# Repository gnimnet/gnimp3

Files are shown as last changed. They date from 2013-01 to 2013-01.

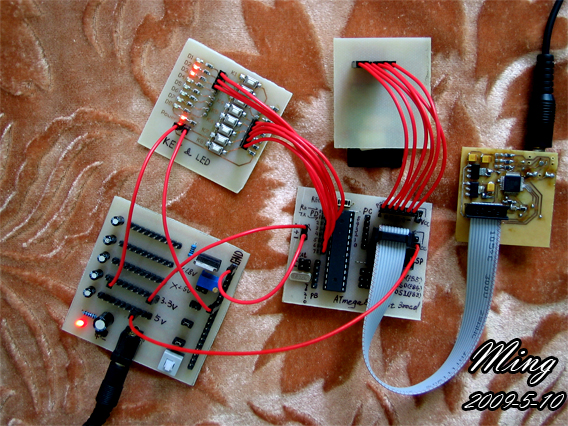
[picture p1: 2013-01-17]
modules.jpeg

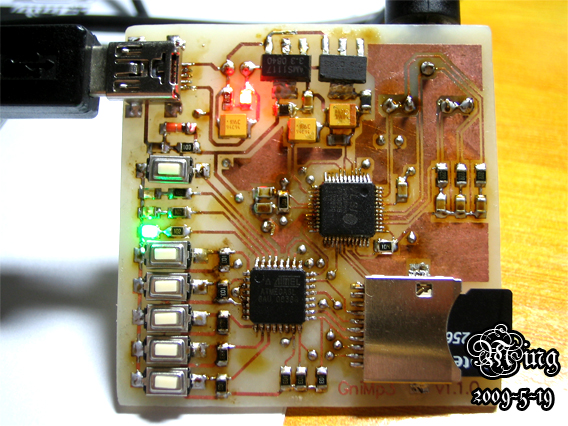
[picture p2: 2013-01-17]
final1.jpeg

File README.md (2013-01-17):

gnimp3
======

基于VS1003的mp3

这是我很满意的一个硬件设计，用自己的MP3还是爽啊
这个电子设计是我相当满意的一个，板子也布的很满意，毕竟单层板...我也不容易啊...这个MP3并没有屏幕，从TF卡里读音乐文件数据，曲目最大支持到70首，有全部循环、单曲循环、随机播放3个模式。供电有个迷你USB口，还有个接排针(我拿来接锂电池)。我是从代码到画PCB，热转印，焊接一手完成，所以这个尤物的纪念意义更大。我现在MP3一直用这个了。

很早就想做一个稍微使用点，感觉牛一点的电子设计，也很早就像打造一个属于自己的MP3，不过硬件功底又不是一时半会能弄起来，从大三开始(其实早些也学)画大把精力在硬件上面，从51到AVR，一直到这个项目，算是我AVR的结业项目了，下来应该要转去玩ARM7了...

其实这个东西做起来很辛苦的，FAT代码是2009寒假写的，然后在3月份就完成了ATmega64的版本(是在一个开发板上，我重写代码并把自己的FAT移植到AVR上)，但PCB的过程却极其郁闷，其实我的设计一直是对的，但是被那万恶的焊锡膏还得一个月没吃好睡好，不过也得谢谢它让我把这个PCB重画了无数遍...最后的体积减小了一倍呢(当然和我最后改用TF卡座也有关)...毕竟我是4月份买到热转印机才开始转印PCB，之前都是万用板。水平也是练出来的么～有志者事竟成乎～

要学习的话，下载链接的东西都有用的；如果只是仿制，那么测试代码没用的，把别的下载下来，然后热转印再把HEX烧到芯片里面就ok...

开发环境
AVR Studio 4.16
WinAVR-20070525
Protel DXP 2004

使用芯片
ATmega8
VS1003B

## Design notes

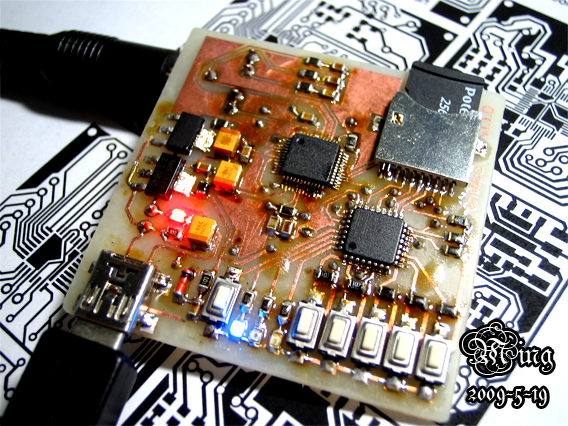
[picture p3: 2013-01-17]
final2.jpeg

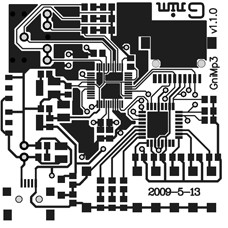
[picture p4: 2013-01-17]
toplayer.jpg

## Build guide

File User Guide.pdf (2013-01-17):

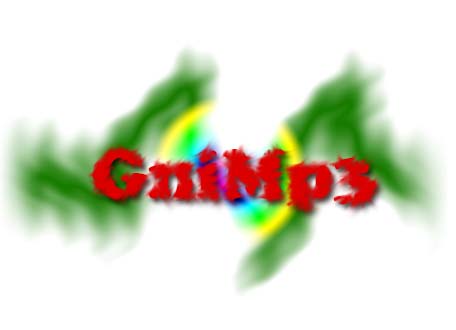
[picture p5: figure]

# Version 1.1.X User Guide By Ming

User Guide(Version 1.1.X)

# MP3 Interface

1 个复位按键
5 个操作按键
1 个电源指示灯
3 个模式指示灯
使用 TF 卡提供音乐数据
使用 3.5mm 耳机
使用 MiniUSB 或跳线供电

1 Key for Reset
5 Keys for Operate
1 LED for Power
3 LEDs for Mode
Use TF card for music data
Use 3.5mm Earphone
MiniUSB or Jumper for power supply

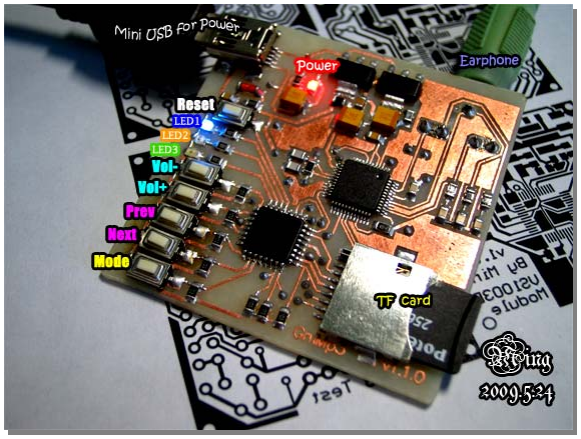
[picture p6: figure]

User Guide(Version 1.1.X)

# Get Start

1. 插入 TF 卡：
在卡座卡入 TF 卡，要求 TF 卡应当格式化为 FAT 文件系统（FAT32/16 均可）
2. 供电：
使用 MiniUSB 或者背面的排针跳线供电，供电电压 3.3v—9v
（建议使用 USB 或者 3.7v 锂电池）
3.MP3 初始化：
在供电后 MP3 将先进行硬件初始化，改步骤如下：
(1)初始化 SD 卡（LED1、LED2、LED3 灭）
(2)初始化 FAT 文件系统信息（LED2、LED3 亮，LED1 灭） (3)初始化 MP3 解码芯片 VS1003B（LED1、LED3 亮，LED2 灭） (4)初始化音乐列表（LED1、LED2 亮，LED3 灭） (5)从播放列表第一首开始进行全部曲目循环播放
对于每一步状态有不同的 LED 指示来确认硬件故障
停在第一步，请检查 SD 卡正确性
停在第二步，请检查 SD 卡格式化的文件系统是否正确，或 SD 卡已坏 停在第三步，可能 VS1003B 解码芯片已坏…
停在第四步，请检查 SD 卡是否无歌曲
4.调整使用：
使用 Mode 按键来切换模式，三个 LED 对应 3 种播放模式 LED1——全部循环，LED2——单曲循环，LED3——随机播放 按下按键按如下顺序切换：
全部循环单曲循环随机播放全部循环……
音量由 Vol-和 Vol+按键来操作，按住不放会进行连续的音量调整
曲目切换由 Prev 和 Next 按键来操作，对于全部循环和单曲循环两个按键按音乐列表切换 上一首和下一首，对于随机模式则任意跳到音乐列表中的一首。

注：
支持音乐文件格式:MP3/WMA/WAV/MID
由于 ATmega8 的 SRAM 限制，音乐列表只保存 70 首，对于 TF 卡多于 70 首音乐的，在搜 索 70 首之后将忽略其他音乐文件。
手最好不要接触到 VS1003B 的晶振引脚，可能引起解码芯片停止工作（可通过复位键重新 初始化解码芯片）
使用电池供电时，在电池快没电的时候状态 LED 会变暗

User Guide(Version 1.1.X)

# PCB Top Layer

这里提供一张 Version 1.1.0 的 PCB 顶层 电路的设计为单层板，这个是第一块通过的板子的 PCB 图

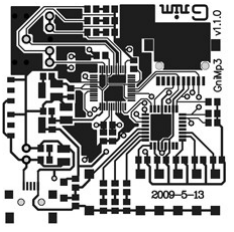
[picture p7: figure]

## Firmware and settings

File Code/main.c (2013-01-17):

#include <avr/io.h>
#include <util/delay.h>
#include "MMC_SD/MMC_SD.h"
#include "FAT/FAT.h"
#include "VS1003B/VS1003B.h"

#define PLAY_FILE_BUF_SIZE	512	//必须是32的整数倍
#define SONG_CLUS_LIST_SIZE	70	//列表大小
#define MAX_SEARCH_DEPTH	5	//文件夹搜索最大深度
#define MODE_NUMS			3	//模式数量

#define LEDPORT	PORTD
#define LEDDDR	DDRD
#define LED1	PD0
#define LED2	PD1
#define LED3	PD2

#define KEYPIN	PIND
#define KEYDDR	DDRD
#define KEY1	PD3
#define KEY2	PD4
#define KEY3	PD5
#define KEY4	PD6
#define KEY5	PD7

void PrintFileName(DWORD DirFristClus,BYTE index);

void SearchSongs();
BYTE ChangePWD(DWORD * PWDClusAdd,WORD Offset);
BYTE PlayFile(DWORD PWDClus,WORD Offset);
void ChangeVol(uchar dec);
uchar GetKey();
void MyDelay(uint ms);
void MaskVS1003B();


DWORD SongClusList[SONG_CLUS_LIST_SIZE];//歌曲所在目录簇号
BYTE SongIndex[SONG_CLUS_LIST_SIZE];//歌曲对应目录项偏移
BYTE TotalNum;//总歌曲数目
uchar NowVol;//当前音量
uchar PlayMode;//播放模式 0--全部循环，1--单曲循环，2--随机播放

int main(void){
	BYTE NowPlay=0,tmp;
	MaskVS1003B();//屏蔽VS1003对SD初始化影响
	NowVol=0x28;
	LEDDDR|=(1<<LED1)|(1<<LED2)|(1<<LED3);//LED端口设为输出
	KEYDDR&=~((1<<KEY1)|(1<<KEY2)|(1<<KEY3)|(1<<KEY4)|(1<<KEY5));//按键端口设为输入
	TCCR0=0x01;//打开Timer0用作随机数种子
	LEDPORT|=(1<<LED1)|(1<<LED2)|(1<<LED3);
	//初始化SD卡信息
	while(SD_Init()!=0)
		;
	LEDPORT=~(1<<LED1);
	//初始化FAT信息
	if(InitFAT()>1){//>2则为FAT12或初始化出错
		while(1);//死循环等待复位
	}
	LEDPORT=~(1<<LED2);
	//初始化VS1003B
	while(VS1003B_Init()==1){
		MyDelay(100);//等待0.1秒重试
	}
	LEDPORT=~(1<<LED3);
	//查找歌曲
	SearchSongs();
	if(TotalNum==0){
		while(1);//没有歌曲
	}
	PlayMode=0;
	LEDPORT=(1<<PlayMode);
	//进入播放循环
	while(1){
		VS1003B_SoftReset();
		tmp=PlayFile(SongClusList[NowPlay],SongIndex[NowPlay]);//播放歌曲
		if(PlayMode==0 || PlayMode==1){
			if(tmp==0 && PlayMode==0){//歌曲播放完毕且为全部循环播放，切换下一首
				if(NowPlay<TotalNum-1)
					NowPlay++;
				else
					NowPlay=0;
			}
			else if(tmp==0xFF){//按下下一首按键
				if(NowPlay<TotalNum-1)
					NowPlay++;
				else
					NowPlay=0;
				MyDelay(10);
			}
			else if(tmp==0xFE){//按下上一首按键
				if(NowPlay==0)
					NowPlay=TotalNum-1;
				else
					NowPlay--;
				MyDelay(10);
			}
		}
		else if(PlayMode==2){
			NowPlay=TCNT0;
			NowPlay%=TotalNum;
		}
	}
	return 0;
}

BYTE GetFileType(DWORD DirFristClus,BYTE index){//获取文件类型函数
	WORD totalnum=GetClusSize()/32;
	struct DIR DIRinfo;
	while(index>=totalnum){
		index-=totalnum;
		DirFristClus=GetNextClus(DirFristClus);//文件位于下一簇
	}
	if(GetDIRinfo(&DIRinfo,DirFristClus,index)!=0){//get file information
		return 0;//Read DIRinfo error!
	}
	if(DIRinfo.DIR_Name[0]==0x00)//End
		return 1;
	if(DIRinfo.DIR_Name[0]==0xE5)//Empty
		return 2;
	if(DIRinfo.DIR_Attr==ATTR_LONG_NAME)//Long File Name
		return 3;
	if(DIRinfo.DIR_Attr==ATTR_VOLUME_ID)
		return 4;
	else if(DIRinfo.DIR_Attr & ATTR_DIRECTORY)
		return 5;
	else{
		if(!(
		(DIRinfo.DIR_Name[8]=='M' && DIRinfo.DIR_Name[9]=='P' && DIRinfo.DIR_Name[10]=='3')||
		(DIRinfo.DIR_Name[8]=='W' && DIRinfo.DIR_Name[9]=='A' && DIRinfo.DIR_Name[10]=='V')||
		(DIRinfo.DIR_Name[8]=='M' && DIRinfo.DIR_Name[9]=='I' && DIRinfo.DIR_Name[10]=='D')||
		(DIRinfo.DIR_Name[8]=='W' && DIRinfo.DIR_Name[9]=='M' && DIRinfo.DIR_Name[10]=='A')
		)){
			return 6;//not a music file
		}
		return 7;//is a music file
	}
	return 8;//unknow file type
}

void SearchSongs(){//查找歌曲函数，用于初始化歌曲列表
	DWORD ClusPWD;//当前工作目录簇号
	BYTE IndexPWD[MAX_SEARCH_DEPTH];//当前工作目录簇号偏移
	BYTE NowLevel;//当前目录级数
	BYTE tmp;
	ClusPWD=GetRootClus();//从根目录开始
	IndexPWD[0]=0;//从0偏移开始找
	NowLevel=0;//当前目录为0级
	TotalNum=0;
	while(1){
		tmp=GetFileType(ClusPWD,IndexPWD[NowLevel]);
		if(tmp==0){//IO错误，重试
			continue;
		}
		else if(tmp==1){//当前目录搜索完毕
			if(NowLevel==0){
				return;//根目录则搜索结束
			}
			else{
				ChangePWD(&ClusPWD,1);//调回上级目录
				NowLevel--;
			}
		}
		else if(tmp==5){
			if(NowLevel<MAX_SEARCH_DEPTH){//未超过最大深度
				ChangePWD(&ClusPWD,IndexPWD[NowLevel]);
				NowLevel++;
				IndexPWD[NowLevel]=1;
			}
		}
		else if(tmp==7){//记录该文件
			SongClusList[TotalNum]=ClusPWD;
			SongIndex[TotalNum]=IndexPWD[NowLevel];
			TotalNum++;
			if(TotalNum>=SONG_CLUS_LIST_SIZE)
				return;//文件列表满
		}
		IndexPWD[NowLevel]++;//处理下一文件
	}
}

BYTE ChangePWD(DWORD * PWDClusAdd,WORD Offset){//切换工作目录函数
	struct DIR DIRinfo;
	if(GetDIRinfo(&DIRinfo,*PWDClusAdd,Offset)!=0){//get file information
		return 1;
	}
	if(DIRinfo.DIR_Attr==ATTR_LONG_NAME || DIRinfo.DIR_Attr!=ATTR_DIRECTORY){
		return 2;//not a dictory
	}
	else{
		*PWDClusAdd=*((WORD*)&DIRinfo.DIR_FstClusHI);
		*PWDClusAdd=*PWDClusAdd<<16;
		*PWDClusAdd+=*((WORD*)&DIRinfo.DIR_FstClusLO);
		if(*PWDClusAdd==0){//Root dir
			*PWDClusAdd=GetRootClus();
		}
		return 0;
	}
}


BYTE PlayFile(DWORD PWDClus,WORD Offset){//播放文件函数
	struct DIR DIRinfo;
	DWORD FileClus,FileSize,HaveSend,ClusSize,SecSend;
	DWORD NowClusSec;
	BYTE Buf[512];
	BYTE SecPerClus,SecCnt;
	uchar Key,Play=1;
	uint Skip=0;
	ClusSize=GetClusSize();//获取簇大小
	SecPerClus=GetSecPerClus();//获取每簇扇区数
	if(GetDIRinfo(&DIRinfo,PWDClus,Offset)!=0){//get file information
		return 1;
	}
	FileClus=*((WORD*)&DIRinfo.DIR_FstClusHI);
	FileClus=FileClus<<16;
	FileClus+=*((WORD*)&DIRinfo.DIR_FstClusLO);
	FileSize=*((DWORD*)DIRinfo.DIR_FileSize);
	HaveSend=0;
	NowClusSec=GetClusSector(FileClus);
	SecCnt=0;
	if(SD_ReadOneSector(NowClusSec,(BYTE*)Buf)!=0)
		return 1;
	SecSend=0;
	while(1){
		if(VS1003B_NeedData() && Play){
			VS1003B_Write32B(&Buf[SecSend]);
			SecSend+=32;
			HaveSend+=32;
			if(HaveSend>=FileSize)
				break;
			if(SecSend>=512){//当前扇区发送完毕
				SecCnt++;//下一扇区
				if(SD_ReadOneSector(NowClusSec+SecCnt,(BYTE*)Buf)!=0)
					return 1;
				if(SecCnt>=SecPerClus){//当前簇发送完毕
					SecCnt=0;
					FileClus=GetNextClus(FileClus);
					NowClusSec=GetClusSector(FileClus);
				}
				SecSend=0;
			}
		}
		else if((Key=GetKey())!=0 && Skip==0){
			if(Key==1){
				ChangeVol(1);//音量减
				Skip=0x1FFF;
			}
			else if(Key==2){
				ChangeVol(0);//音量加
				Skip=0x1FFF;
			}
			else if(Key==3){
				VS1003B_Fill2048Zero();
				return 0xFE;//上一首
			}
			else if(Key==4){
				VS1003B_Fill2048Zero();
				return 0xFF;//下一首
			}
			else if(Key==5){
				PlayMode=(PlayMode+1) % MODE_NUMS;//切换模式
				LEDPORT=(1<<PlayMode);
				Skip=0x5FFF;
			}
		}
		if(Skip!=0)
			Skip--;
	}
	return 0;
}

void ChangeVol(uchar dec){//调整音量函数
	uint tmp;
	if(dec){
		if(NowVol<0xFE)
			NowVol+=2;
	}
	else{
		if(NowVol>0)
			NowVol-=2;
	}
	tmp=NowVol;
	tmp=tmp<<8;
	tmp+=NowVol;
	VS1003B_SetVolume(tmp);
}

uchar GetKey(){
	if( (KEYPIN & (1<<KEY1))==0){
		return 1;
	}
	else if( (KEYPIN & (1<<KEY2))==0){
		return 2;
	}
	else if( (KEYPIN & (1<<KEY3))==0){
		return 3;
	}
	else if( (KEYPIN & (1<<KEY4))==0){
		return 4;
	}
	else if( (KEYPIN & (1<<KEY5))==0){
		return 5;
	}
	return 0;
}

void MyDelay(uint ms){
	while(ms--)
		_delay_ms(ms);
}

void MaskVS1003B(){
	DDRC|=(1<<PC2);
	PORTC|=(1<<PC2);
}

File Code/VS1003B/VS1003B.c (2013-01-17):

/*********************************************************
Write By Ming	2009-3-23
*********************************************************/
#include<avr/io.h>
#include<util/delay.h>
#include"VS1003B.h"

//**********VS1003B寄存器地址声明**********//
#define MODE 		0x00	//模式控制
#define STATUS		0x01	//VS1003状态
#define BASS		0x02	//内置低音/高音增强器
#define CLOCKF		0x03	//时钟频率+倍频数
#define DECODE_TIME	0x04	//每秒解码次数
#define AUDATA		0x05	//Misc.音频数据
#define WRAM		0x06	//RAM 写/读
#define WRAMADDR	0x07	//RAM 写/读基址
#define HDAT0		0x08	//流头数据0
#define HDAT1		0x09	//流头数据1
#define AIADDR		0x0A	//用户代码起始地址
#define VOL			0x0B	//音量控制
#define AICTRL0		0x0C	//应用控制寄存器0
#define AICTRL1		0x0D	//应用控制寄存器1
#define AICTRL2		0x0E	//应用控制寄存器2
#define AICTRL3		0x0F	//应用控制寄存器3

//**********VS1003B寄存器值声明**********//
#define TREMBLE_VALUE	8		/* 0~15, 8 means off  */
#define TREMBLE_LOW_FS	8		/* 0~15, 0Hz-15KHz, lower frequency of tremble enhancement */
#define BASS_VALUE		0		/* 0~15, 0 means off  */
#define BASS_HIGH_FS	8		/* 2~15, up limit frequency of bass enhancement */
#define DEFAULT_BASS_TREMBLE ((TREMBLE_VALUE<<12)|(TREMBLE_LOW_FS<<8)|(BASS_VALUE<<4)|(BASS_HIGH_FS))

#define CLOCK_REG		0xE000	//PLL设定值，XTALI * 4.5
#define DEFAULT_VOLUME	0x2828	//默认音量值
#define MUTE_VOLUME		0xFEFE	//静音值

//**********MCU对VS1003B的引脚设定**********//
#define XCS_DDR		DDRC
#define XCS_PORT	PORTC
#define XCS			PC1

#define XRESET_DDR  DDRC
#define XRESET_PORT PORTC
#define XRESET		PC4

#define DREQ_DDR	DDRC
#define DREQ_PORT	PORTC
#define DREQ_PIN	PINC
#define DREQ		PC3

#define XDCS_DDR	DDRC
#define XDCS_PORT	PORTC
#define XDCS		PC2

#define SCK_DDR		DDRB
#define SCK_PORT	PORTB
#define SCK			PB5

#define MOSI_DDR	DDRB
#define MOSI_PORT	PORTB
#define MOSI		PB3

#define MISO_DDR	DDRB
#define MISO_PORT	PORTB
#define MISO		PB4

#define SS_DDR		DDRB
#define SS			PB2

#define XCS_H()		XCS_PORT |= (1<<XCS)
#define XCS_L()		XCS_PORT &= ~(1<<XCS)

#define XRESET_H()	XRESET_PORT |= (1<<XRESET)
#define XRESET_L()	XRESET_PORT &= ~(1<<XRESET)

#define XDCS_H()    XDCS_PORT |=  (1<<XDCS)
#define XDCS_L()    XDCS_PORT &= ~(1<<XDCS)

//**********内部函数**********//
void VS1003B_SPI_SetSpeedLow(){//设定SPI工作频率为1/128时钟频率(低速)
	SPCR = (1<<SPE)|(1<<MSTR)|(1<<SPR1)|(1<<SPR0);
	SPSR &= ~(1<<SPI2X);
}

void VS1003B_SPI_SetSpeedHigh(){//设定SPI工作频率为1/2时钟频率(高速)
	SPCR = (1<<SPE)|(1<<MSTR);
	SPSR |= (1<<SPI2X);
}

uchar VS1003B_ByteRW(uchar data){//写一字节数据，并把交换数据读出
	SPDR=data;
	while(!(SPSR & (1<<SPIF)));
	return SPDR;
}

void VS1003B_Port_Init(){//初始化端口函数
	XCS_PORT |= (1<<XCS);
	XRESET_PORT |= (1<<XRESET);
	DREQ_PORT |= (1<<DREQ);
	XDCS_PORT |= (1<<XDCS);

	XCS_DDR |= (1<<XCS);
	XRESET_DDR |= (1<<XRESET);
	DREQ_DDR &= ~(1<<DREQ);
	XDCS_DDR |= (1<<XDCS);
	SCK_DDR |= (1<<SCK);
	MOSI_DDR |= (1<<MOSI);
	MISO_DDR &= ~(1<<MISO);
	SS_DDR |= 1<<SS;
}

//**********接口函数**********//
void VS1003B_WriteCMD(uchar addr,uint dat){//向VS1003B写寄存器
	XDCS_H();
	XCS_L();
	VS1003B_ByteRW(0x02);
	VS1003B_ByteRW(addr);
	VS1003B_ByteRW(dat>>8);
	VS1003B_ByteRW(dat);
	XCS_H();
}

uint VS1003B_ReadCMD(uchar addr){//读VS1003B寄存器
	uint rtn;
	XDCS_H();
	XCS_L();
	VS1003B_ByteRW(0x03);
	VS1003B_ByteRW(addr);
	rtn = VS1003B_ByteRW(0xFF);
	rtn <<= 8;
	rtn += VS1003B_ByteRW(0xFF);
	XCS_H();
	return rtn;
}

void VS1003B_Fill2048Zero(){//给VS1003B发送2048个数据0
	unsigned char i,j;
	for(i=0;i<64;i++){
		XDCS_L();
		while(VS1003B_NeedData()==0);
		for(j=0;j<32;j++){
			VS1003B_ByteRW(0x00);
		}
		XDCS_H();
	}
}

void VS1003B_Write32B(uchar * buf){//给VS1003B发送32字节数据，参数为缓冲首地址
	uchar n = 32;
	XDCS_L();
	while(n--){
		VS1003B_ByteRW(*buf++);
	}
	XDCS_H();
}

void VS1003B_SoftReset(){//软复位
	VS1003B_SPI_SetSpeedHigh();
	VS1003B_WriteCMD(MODE,0x0804);
	_delay_ms(20);
}

/*
uint VS1003B_ReadDecodeTime(){//读每秒解码次数
	VS1003B_SPI_SetSpeedHigh();
	return VS1003B_ReadCMD(DECODE_TIME);
}
*/

uchar VS1003B_NeedData(){//检查VS1003B是否需要数据，返回1--需要，0--不需要
	if(DREQ_PIN & (1<<DREQ))
		return 1;
	else
		return 0;
}

void VS1003B_SetVolume(uint vol_val){//设定音量
	VS1003B_SPI_SetSpeedHigh();
	VS1003B_WriteCMD(VOL,vol_val);	
}

uchar VS1003B_Init(){//初始化VS1003B,返回0--成功，1--失败
	uchar retry;
	VS1003B_Port_Init();//初始化端口

	XRESET_L();//硬复位
	_delay_ms(20);
	XRESET_H();

	VS1003B_SPI_SetSpeedLow();//设定SPI低速
	_delay_ms(20);

	retry=0;
	while(VS1003B_ReadCMD(CLOCKF) != CLOCK_REG){//设定PLL寄存器，选择工作频率
		VS1003B_WriteCMD(CLOCKF,CLOCK_REG);
		if(retry++ >10 )return 1;
	}
	_delay_ms(20);
	VS1003B_WriteCMD(AUDATA,0x000A);

	retry=0;
	while(VS1003B_ReadCMD(VOL) != MUTE_VOLUME){	//静音
		VS1003B_WriteCMD(VOL,MUTE_VOLUME);
		if(retry++ >10 )return 1;
	}
	VS1003B_WriteCMD(AUDATA,0xAC45);//软启动

	retry=0;
	while(VS1003B_ReadCMD(VOL) != DEFAULT_VOLUME){//设定默认音量
		VS1003B_WriteCMD(0x0b,DEFAULT_VOLUME);
		if(retry++ >10 )return 1;
	}

	retry=0;
	while(VS1003B_ReadCMD(MODE) != 0x0800){//设定功能寄存器
		VS1003B_WriteCMD(MODE,0x0800);
		if(retry++ >10 )return 1;
	}
	_delay_ms(1);

	retry=0;
	while(VS1003B_ReadCMD(BASS) != DEFAULT_BASS_TREMBLE)	/* set bass/tremble register */
	{
		VS1003B_WriteCMD(BASS,DEFAULT_BASS_TREMBLE);
		if(retry++ >10 )return 1;
	}
	_delay_ms(20);

	VS1003B_SoftReset();	/* A soft reset */
	_delay_ms(20);

	VS1003B_SPI_SetSpeedHigh();//设定SPI高速

	return 0;
}
